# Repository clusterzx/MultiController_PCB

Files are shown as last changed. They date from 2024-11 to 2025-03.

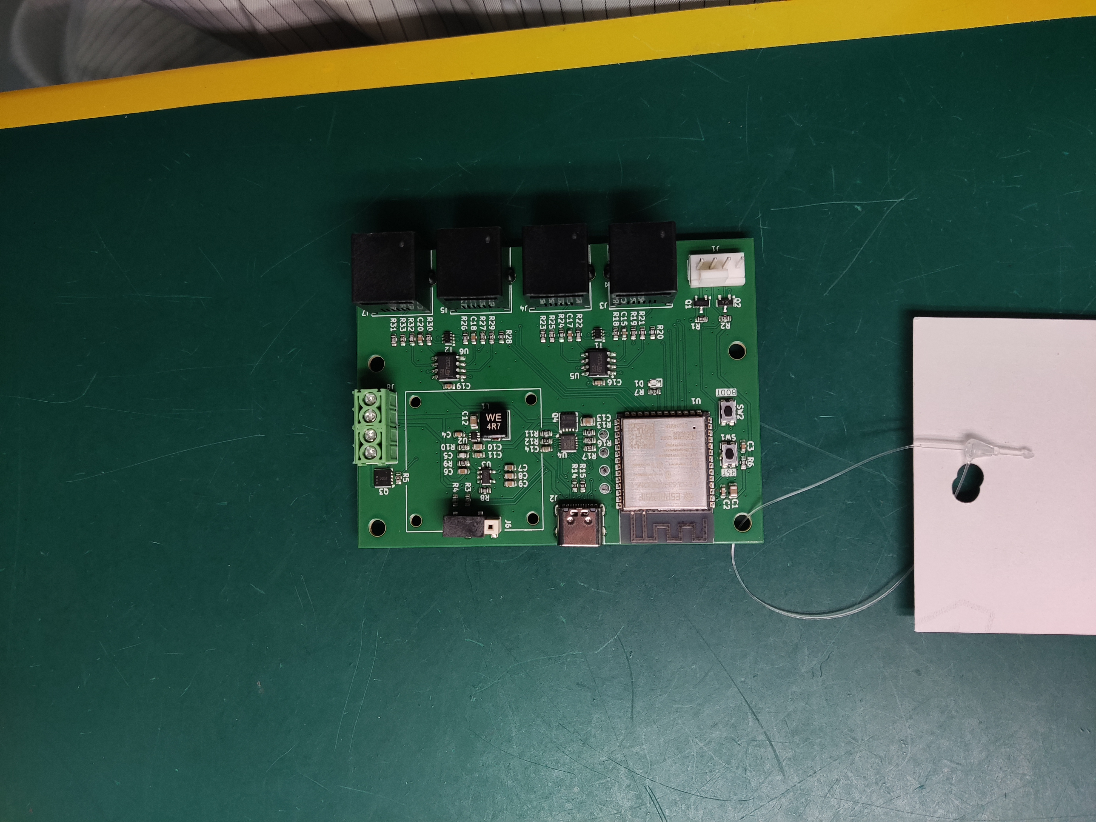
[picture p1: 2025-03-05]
Hardware/documentation/T-X20W345372A_JLCPCB/T-X20W345372A (5).jpg

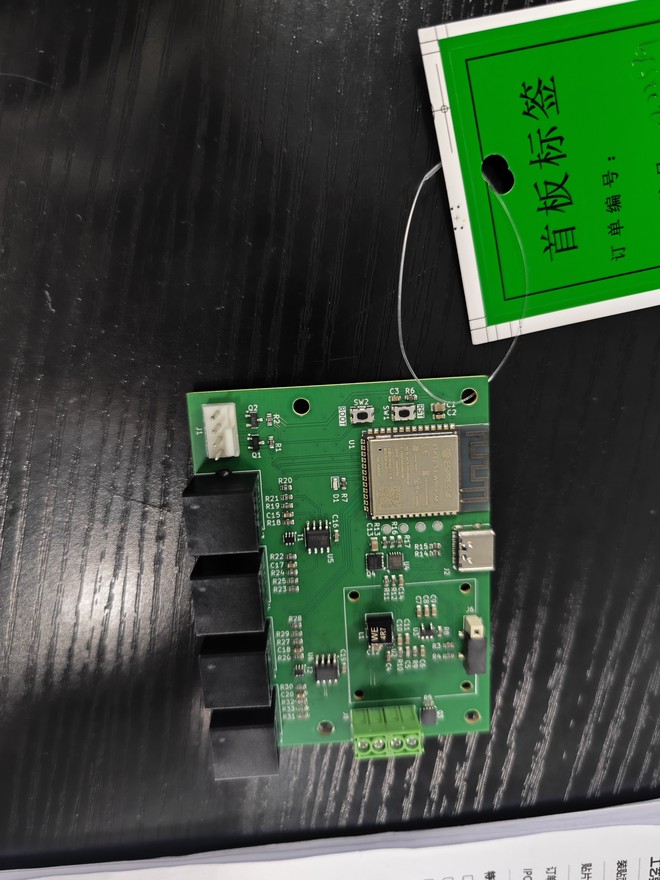
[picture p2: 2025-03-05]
Hardware/documentation/T-X20W345372A_JLCPCB/T-X20W345372A (1).jpg

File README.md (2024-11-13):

# MultiController_PCB
Design Files für Review Auftrag.

**Ziel des Controllers:**

 1. Steuerung von Geräten über PWM 0-10V und/oder DAC 0-10V . Die Geräte bekommen ihre Spannungsversorgugn von einer externen Quelle (somit reines Steuersignal)
 2. Steuerung von handelsüblichen PC Fans (PWM) über den Molexanschluss (müssten 12V sein).
 3. Steuerung der PWM Signale unabhängig von einander. Bedeutet z.B. das auf RJ Jack 1 PWM 50% liegen und auf RJ 2 nichts dafür auf RJ 3-4 100%.
 4. Steuerung des Terminalblocks 3,5,12V (an/aus) (dort liegt immer nur 1 Verbraucher an)
 5. Anschluss eines optionalen OLED Displays und steuerung über ESP32

**ChatGPT generierte Zusammenfassung des Auftragschats:**
## Zusammenfassung

Dieses Dokument fasst die finalen Funktionen und Änderungen für das Multicontroller PCB-Projekt zusammen.

## Finalisierte Funktionen

1. **Spannungsversorgung**:
   - USB-C als primäre Stromquelle mit Power Delivery (PD) für 12V.
   - Step-Down-Konverter auf 5V und ein LDO (Low Dropout Regulator) auf 3.3V.
   - Optionaler Boost-Konverter für zusätzliche 12V, falls mehr Leistung benötigt wird.

2. **RJ14-Anschlüsse (6P4C)**:
   - Steuerung von Geräten über PWM und GND.
   - Modularer RJ14-Anschluss (6P4C) für Kompatibilität mit Standardkabeln (1:1 oder crossed).

3. **Schraubklemmen für stärkere Stromverbindungen**:
   - Verwendung von Phoenix-Klemmen, um dickere Kabel (z.B. AWG 14) anzuschließen.
   - Schraubklemmen mit 3.5mm Pitch für Zuverlässigkeit und eine robuste Verbindung.

4. **ESP32-S3 Mikrocontroller**:
   - Externer DAC hinzugefügt, da der ESP32-S3 keinen integrierten DAC hat.
   - Reset- und Boot-Knöpfe am Board integriert.
   - Alle benötigten GPIOs auf PWM-Kompatibilität überprüft.

5. **Steuerung von PC-Lüftern und anderen Geräten**:
   - 12V-Anschluss für PC-Lüftersteuerung (optional per Software schaltbar).
   - Mehrere PWM-Ausgänge sowie ein analoger Modus über eine Operationsverstärker- und Kondensator-Schaltung.

6. **Montagemöglichkeiten und Board-Größe**:
   - Boardgröße: 60 x 80 mm.
   - Befestigungslöcher an allen vier Ecken für einfache Gehäusemontage.
   - Layout so gestaltet, dass ein Gehäuse einfach konstruiert werden kann.

## Wichtige Änderungen im Verlauf

- **Änderung des PD-Controllers**: Der ursprünglich geplante PD-Controller (AP33771C) war nicht verfügbar; daher Wechsel zum besser verfügbaren HUSB238.
- **Änderungen an den RJ14-Buchsen**: Diskussion über verschiedene RJ-Typen (RJ11, RJ12, RJ14); endgültige Entscheidung für RJ14 mit 6P4C für bessere Kompatibilität.
- **Überarbeitung der Schraubklemmen**: Zunächst wurden filigrane Klemmen verwendet; später durch robustere Phoenix-Schraubklemmen ersetzt.
- **Dual-Assembly-Option**: Ursprünglich wurden zwei mögliche Bestückungsoptionen (JLCPCB und Aisler) in Betracht gezogen; aufgrund des Preisvorteils letztendlich für JLCPCB entschieden.
- **Optimierung des KiCad-Projekts**: Letzte Anpassungen und Testpunkte (TP) wurden geklärt; Bauteilzuordnungen für die Bestellung bei JLCPCB überprüft.

---

Diese Zusammenfassung bietet eine vollständige Übersicht über die finalen Funktionen und Änderungen, die im Verlauf des Projekts vorgenommen wurden.

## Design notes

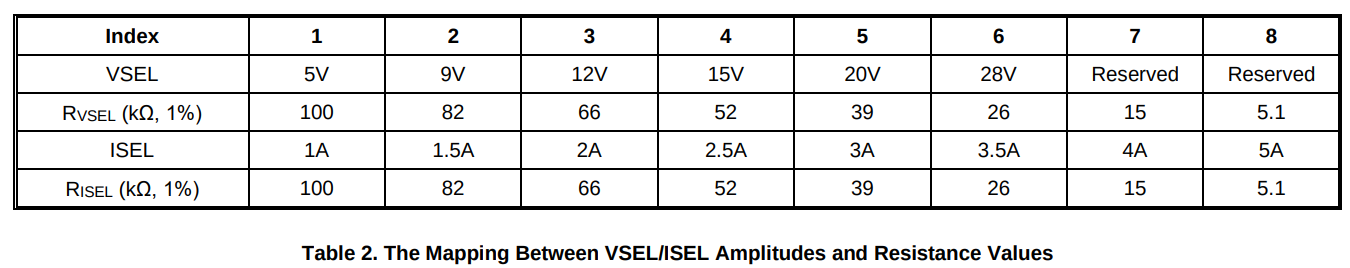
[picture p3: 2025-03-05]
Hardware/documentation/AP33771C_VSEL_ISEL.png

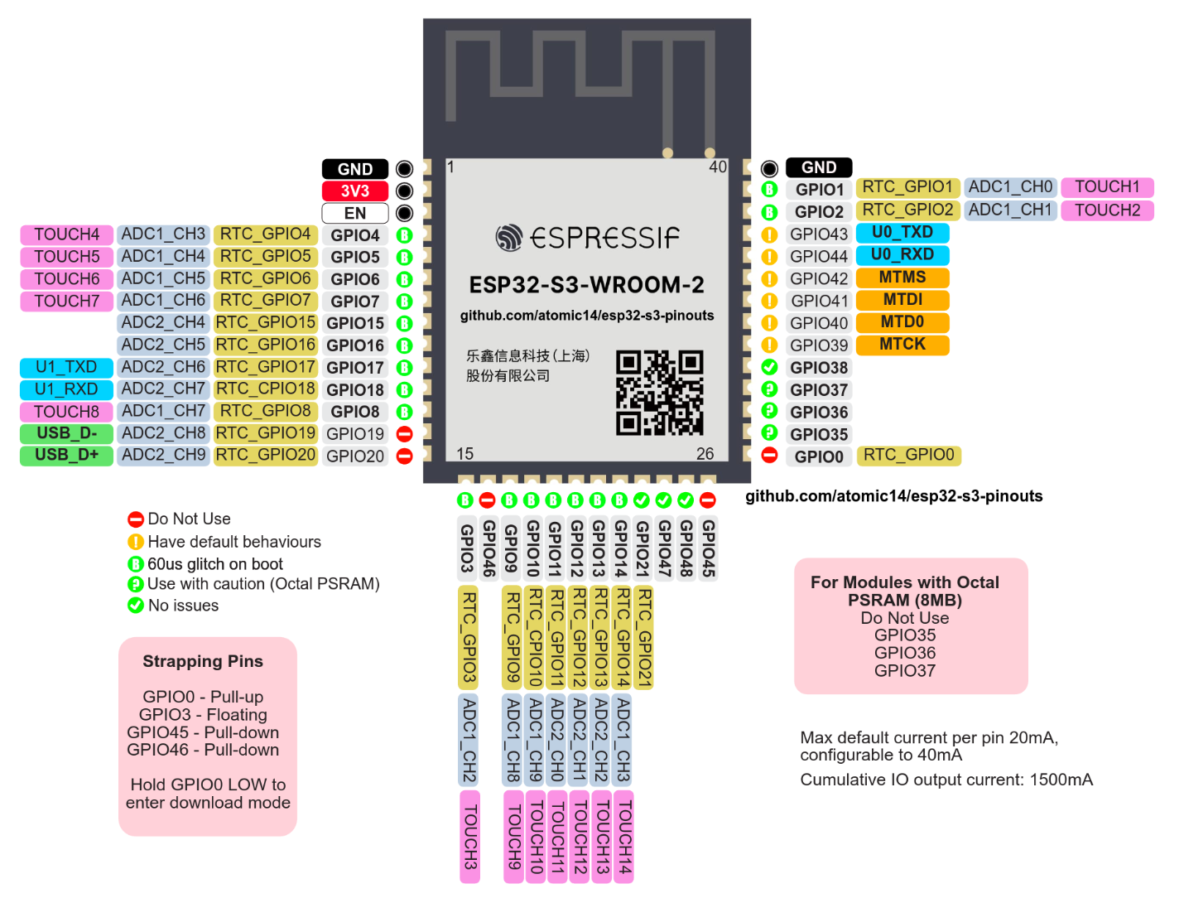
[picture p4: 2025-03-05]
Hardware/documentation/ESP32-S3-WROOM_pinout.png

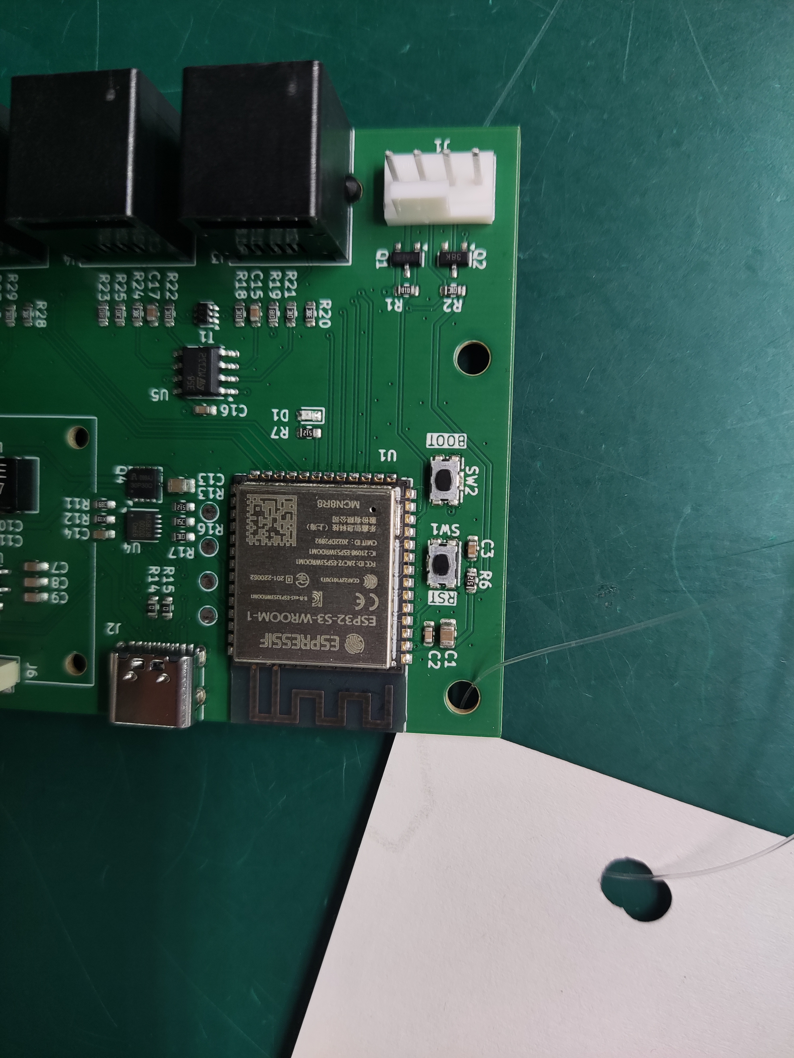
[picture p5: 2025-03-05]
Hardware/documentation/T-X20W345372A_JLCPCB/T-X20W345372A (7).jpg

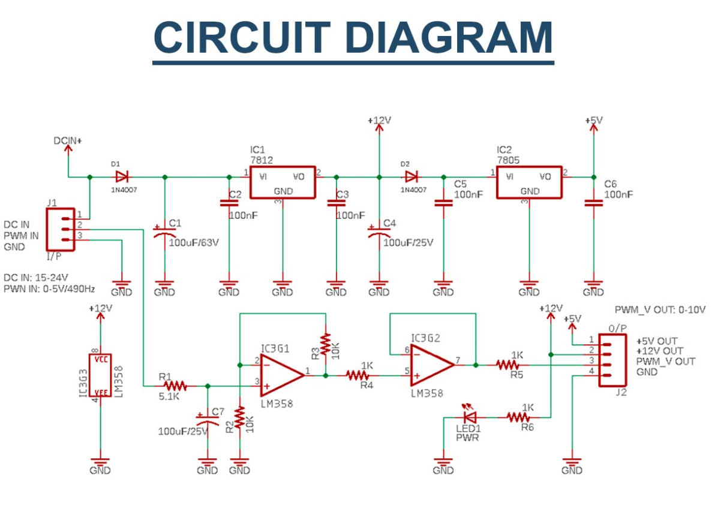
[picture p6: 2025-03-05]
Hardware/documentation/Amazon_PWMto0-10V.png

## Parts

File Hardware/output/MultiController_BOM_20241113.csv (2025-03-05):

Reference | Value | Footprint | Qty | DNP | JLCPCB Part # | MPN
C1,C12,C13 | 22u | Capacitor_SMD:C_0805_2012Metric | 3
C2,C4,C11,C16,C19 | 100n | Capacitor_SMD:C_0603_1608Metric | 5
C3,C14 | 1u | Capacitor_SMD:C_0603_1608Metric | 2
C5 | 22p | Capacitor_SMD:C_0603_1608Metric | 1
C6,C7,C8,C9,C10 | 10u | Capacitor_SMD:C_0603_1608Metric | 5
C15,C17,C18,C20 | 2u2 | Capacitor_SMD:C_0603_1608Metric | 4
D1 | KT-0603R | LED_SMD:LED_0603_1608Metric | 1 |  | C2286 | KT-0603R
J1 | PC-Fan | MultiController_customFP:Molex_KK-254_0470531000_1x04_P2.54mm_Vertical | 1 |  | C3025061 | 0470531000
J2 | USB_C_Receptacle_USB2.0_16P | Connector_USB:USB_C_Receptacle_XKB_U262-16XN-4BVC11 | 1 |  | C319148 | U262-161N-4BVC11
J3,J4,J5,J7 | 6P4C | MultiController_customFP:RJ14_ADAMTECH_MTJ-642BX2_Horizontal | 4 |  | C6600933 | MTJ-642BX2
J6 | OLED | MultiController_customFP:PinSocket_1x04_P2.54mm_Vertical_SMD_drill_Pin1Right | 1 |  | C7219867 | BG306-04-A-1-0400-L-B
J8 | Screw_Terminal_01x04 | TerminalBlock_Phoenix:TerminalBlock_Phoenix_PT-1,5-4-3.5-H_1x04_P3.50mm_Horizontal | 1 |  |  | 1984633
L1 | 4.7uH | Inductor_SMD:L_Wuerth_HCI-5040 | 1 |  | C2651181 | 744316470
Q1 | BSS83P | Package_TO_SOT_SMD:SOT-23 | 1 |  | C2932927 | BSS83PH6327
Q2 | BSS138 | Package_TO_SOT_SMD:SOT-23 | 1 |  | BSS138BK | C5224267
Q3 | DMN3008SFG | Package_SON:Diodes_PowerDI3333-8 | 1 |  | C384563 | DMN3008SFG-7
Q4 | AP30P30Q | Package_SON:Diodes_PowerDI3333-8 | 1 |  | C471913 | AP30P30Q
R1,R8 | 100k | Resistor_SMD:R_0603_1608Metric | 2
R2,R3,R4,R5,R10,R17,R18,R21,R22,R25,R26,R29,R30,R33 | 10k | Resistor_SMD:R_0603_1608Metric | 14
R6,R7,R13 | 5k1 | Resistor_SMD:R_0603_1608Metric | 3
R9 | 52k3 | Resistor_SMD:R_0603_1608Metric | 1
R11 | 49k9 | Resistor_SMD:R_0603_1608Metric | 1
R12 | 10r | Resistor_SMD:R_0603_1608Metric | 1
R14,R15 | 0r | Resistor_SMD:R_0603_1608Metric | 2
R16 | 14k | Resistor_SMD:R_0603_1608Metric | 1
R19,R23,R27,R31 | 1k | Resistor_SMD:R_0603_1608Metric | 4
R20,R24,R28,R32 | 20k | Resistor_SMD:R_0603_1608Metric | 4
SW1 | RESET | Button_Switch_SMD:SW_Push_1P1T_NO_CK_KMR2 | 1 |  | C72443 | KMR221GLFS
SW2 | BOOT | Button_Switch_SMD:SW_Push_1P1T_NO_CK_KMR2 | 1 |  | C72443 | KMR221GLFS
T1,T2 | BSS138DW | Package_TO_SOT_SMD:SOT-363_SC-70-6 | 2 |  | C5362112 | BSS138DW
U1 | ESP32-S3-WROOM-1 | MultiController_customFP:ESP32-S3-WROOM-1 | 1 |  | C2913201 | ESP32-S3-WROOM-1-N8R8
U2 | TPS562202 | Package_TO_SOT_SMD:SOT-563 | 1 |  | C2877547 | TPS562202
U3 | AP2112K-3.3 | Package_TO_SOT_SMD:SOT-23-5 | 1 |  | C51118 | AP2112K-3.3TRG1
U4 | HUSB238 | Package_DFN_QFN:DFN-10-1EP_3x3mm_P0.5mm_EP1.65x2.38mm | 1 |  | C7471904 | HUSB238_002DD
U5,U6 | LM358 | Package_SO:SOIC-8_3.9x4.9mm_P1.27mm | 2 |  | C9418 | LM358DT

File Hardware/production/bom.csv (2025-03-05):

Designator | Footprint | Quantity | Value | LCSC Part #
C1, C12, C13 | 0805 | 3 | 22u
C10, C6, C7, C8, C9 | 0603 | 5 | 10u
C11, C16, C19, C2, C4 | 0603 | 5 | 100n
C14, C3 | 0603 | 2 | 1u
C15, C17, C18, C20 | 0603 | 4 | 2u2
C5 | 0603 | 1 | 22p
D1 | 0603 | 1 | KT-0603R | C2286
J1 | Molex_KK-254_0470531000_1x04_P2.54mm_Vertical | 1 | PC-Fan | C3025061
J2 | USB_C_Receptacle_XKB_U262-16XN-4BVC11 | 1 | USB_C_Receptacle_USB2.0_16P | C319148
J3, J4, J5, J7 | RJ14_Connfly_DS1133-S4_Horizontal | 4 | 6P4C | C6600933
J6 | PinSocket_1x04_P2.54mm_Vertical_SMD_drill_Pin1Right | 1 | OLED | C7219867
J8 | TerminalBlock_Phoenix_PT-1,5-4-3.5-H_1x04_P3.50mm_Horizontal | 1 | Screw_Terminal_01x04 | 1984633
L1 | L_Wuerth_HCI-5040 | 1 | 4.7uH | C2651181
Q1 | SOT-23 | 1 | BSS83P | C2932927
Q2 | SOT-23 | 1 | BSS138 | BSS138BK
Q3 | Diodes_PowerDI3333-8 | 1 | DMN3008SFG | C384563
Q4 | Diodes_PowerDI3333-8 | 1 | AP30P30Q | C471913
R1, R8 | 0603 | 2 | 100k
R10, R17, R18, R2, R21, R22, R25, R26, R29, R30, R33, R5 | 0603 | 12 | 10k
R11 | 0603 | 1 | 49k9
R12 | 0603 | 1 | 10r
R13, R6, R7 | 0603 | 3 | 5k1
R14, R15 | 0603 | 2 | 0r
R16 | 0603 | 1 | 14k
R19, R23, R27, R31 | 0603 | 4 | 1k
R20, R24, R28, R32 | 0603 | 4 | 20k
R3, R4 | 0603 | 2 | 2k2
R9 | 0603 | 1 | 52k3
SW1 | SW_Push_1P1T_NO_CK_KMR2 | 1 | RESET | C72443
SW2 | SW_Push_1P1T_NO_CK_KMR2 | 1 | BOOT | C72443
T1, T2 | SOT-363_SC-70-6 | 2 | BSS138DW | C5362112
U1 | ESP32-S3-WROOM-1 | 1 | ESP32-S3-WROOM-1 | C2913201
U2 | SOT-563 | 1 | TPS562202 | C2877547
U3 | SOT-23-5 | 1 | AP2112K-3.3 | C51118
U4 | DFN-10-1EP_3x3mm_P0.5mm_EP1.65x2.38mm | 1 | HUSB238 | C7471904
U5, U6 | SOIC-8_3.9x4.9mm_P1.27mm | 2 | LM358 | C9418

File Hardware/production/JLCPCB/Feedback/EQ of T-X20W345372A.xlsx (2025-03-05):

T-X20W345372A-8sets
No. Item | Mfg Part | Package/Footprint | Description / Value | Designator | Qty per board | Total Qty | Qty Received | Instructions / Notes | Assembly Question | Reply from Customer
10 | MTJ-642BX2 | RJ14_ADAMTECH_MTJ-642BX2_Horizontal | 6P4C『 』RJ connector, 6P4C (6 positions 4 connected), RJ13/RJ14 | J3,J4,J5,J7 | 4 | 32 | 35 | C6600933 | We bought the component MTJ-642BX2, but it can't match the land pattern on the board. Please refer to the recommended design in the data-sheet, the distance marked in red should be 5.55mm, but you only designed it for 4.97mm in the Gerber file, so the pins can't be inserted into the holes. Please provide us a replacement component part number.
29 | KMR221GLFS | SW_Push_1P1T_NO_CK_KMR2 | RESET『 』Push button switch, generic, two pins | SW1 | 1 | 8 | 9 | C72443 | We bought the component KMR221GLFS, but it can't match the land pattern on the board. Please refer to the recommended design in the data-sheet, you designed one less pad in the Gerber file. Can we solder the component we bought? And please change the design in your next order.
30 | KMR221GLFS | SW_Push_1P1T_NO_CK_KMR2 | BOOT『 』Push button switch, generic, two pins | SW2 | 1 | 8 | 9 | C72443 | We bought the component KMR221GLFS, but it can't match the land pattern on the board. Please refer to the recommended design in the data-sheet, you designed one less pad in the Gerber file. Can we solder the component we bought? And please change the design in your next order.

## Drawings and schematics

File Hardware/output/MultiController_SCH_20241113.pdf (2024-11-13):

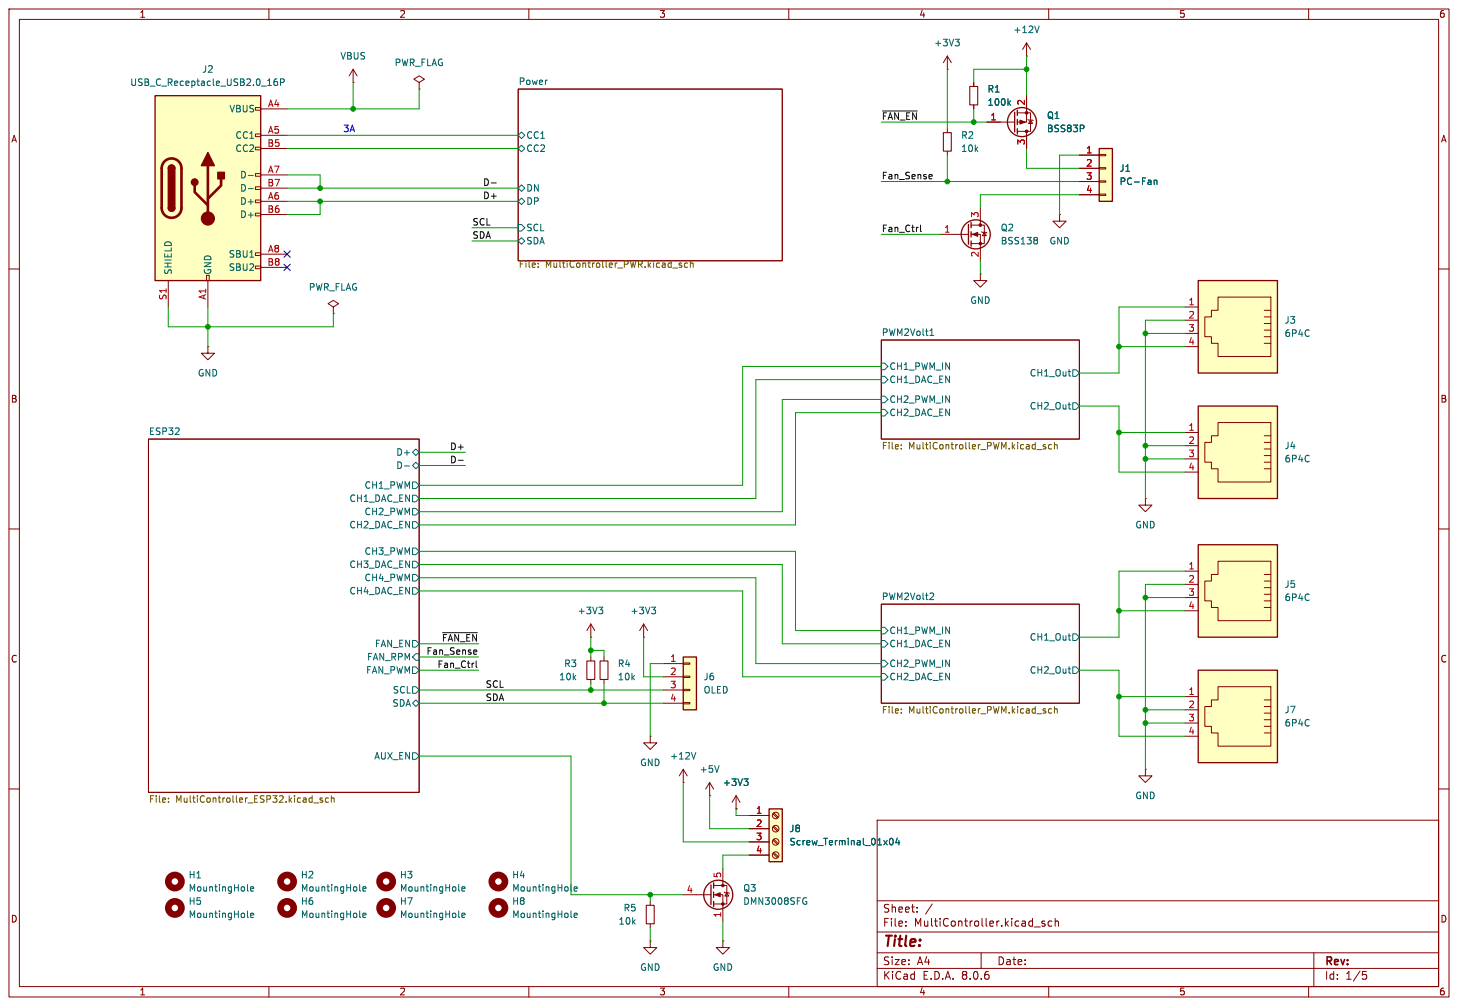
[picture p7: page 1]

Id: 1/5 Title: File: MultiController.kicad_sch Sheet: / D+D- SCL SDA CH1_PWM

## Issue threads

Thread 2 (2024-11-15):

Current limitation and trace width

olli177, 2024-11-15:
Following this calculation for the heating of PCB traces:

[ I[A] / (K x h[mm]^0,5 x b[mm]^0,64) ] ^2= ΔT[K] with K = 3,3 for 2-Layer PCBs and 2,25A as current value I[A]

The PCB trace of VBUS would heat up to ΔT[K] = 40 °C for 35um and ΔT[K] = 20°C for 70um

Idea: Increasing trace width to 0.5mm or even more would decrease the thermal heating by 10°C.

Knochi, 2024-11-19:
High Current paths track width increased to 0.6mm for VBus, 12V and +5V.

Closed 2024-11-19.

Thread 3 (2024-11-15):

I2C Pull-Up

olli177, 2024-11-15:
Reduce pull-up resistor from 10k to 2k2 (or even 1k) if using 400kHz I2C frequency.

Knochi, 2024-11-19:
done.

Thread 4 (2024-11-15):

J6 footprint

olli177, 2024-11-15:
J6 is a SMT variant with through holes?
Either use SMT pin header or THT pin header but two variants in one footprint?

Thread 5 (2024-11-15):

Optional: Avoid +12V on MCU

olli177, 2024-11-15:
Recommendation is to implement one npn transistor instead of using of low-active FAN_EN signal.
Deactivation of this signal (by pulling it High) would be by setting the corresponding GPIO to high-ohmic which is not really common.

With npn transistor, you can use setting the GPIO high (enable FAN) oder low (disable FAN).

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

clusterzx, 2024-11-19:
Resolved

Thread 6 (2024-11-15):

Silkscreen out of PCB dimensions

olli177, 2024-11-15:
The silkscreens of J3, J4, J5, J7 are not placed on the PCB so they are not printed on it during PCB production

Closed 2024-11-19.

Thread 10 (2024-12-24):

Molex Fan lässt sich nicht ausschalten / komisches Verhalten

clusterzx, 2024-12-24:
Wenn ich den 12V PWM Molexanschluss steuere ist bspw. der Lüfter bei 1% auf 960RPM, wenn ich dann auf 0% runter Regel dann ist RPM bei ca 3000 und er läuft viel schneller. Bei 99% ist der Lüfter auf ca 8000RPM, bei 100% fällt er ab auf 6000 und wird langsamer.

Zudem läuft der Lüfter ununterbrochen. Wie kann man den ausschalten? FAN_EN auf Low bringt nichts.

Knochi, 2025-01-05:
Noch mal hier.
Laut [Intel Spezifikation](https://www.intel.com/content/dam/support/us/en/documents/intel-nuc/intel-4wire-pwm-fans-specs.pdf) ist der PWM Bereich nur zwischen 20%-100% definiert. Bei  einem 0-PWM soll der Lüfter auf 100% hochdrehen.
Die Frequenz ist mit 25Hz +- 3Hz spezifiziert.

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

### FAN_EN
Hierüber kann die Spannungszufuhr zum Lüfter (pin2) gesteuert werden. Der Eingang ist Low-Activ, d.h. er muss auf Low gezogen werden, damit Q1 leitet. Ein HIGH genügt allerdings nicht, um den PMOS zum sperren bringen, da UGS dann immer noch -8.7V beträgt. UGS muss >2V sein. Dazu muss IO8 auf HIGH-Z (input ohne pullup) geschaltet werden. In einer Revision kann noch ein transistor zwischengeschaltet werden, der dann die Polarität umkehrt und HIGH/LOW pegel erlaubt.

### FAN_SENSE
Hier kann die aktuelle Drehzahl des Lüfters gemessen werden. Der Ausgang des Lüfters gibt zwei Pulse pro Umdrehung aus.

### FAN_CTRL
Hier kann ein PWM Signal angelegt werden um einen 4-pin Lüfter zu steuern. Die Frequenz sollt ebei 25Hz +-3Hz liegen. Der definierte Bereich liegt zwischen 20-100%. Bei 0-PWM dreht der Lüfter auf 100% (Notbetrieb).

Closed 2025-03-05.

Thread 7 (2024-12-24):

Voltage Drop mit FAN auf Ch1,2,3,4

clusterzx, 2024-12-24:
Szenario:

Ich kann ohne Probleme ein 0-10V PWM Signal erzeugen und steuern auf bspw. Ch1.
Sobald ich aber z.B. diesen Lüfter anschließe:
https://www.lueftungsmarkt.de/ruck-em-160-ec-02-rohrventilator

Droppt die Voltage von 10V auf 4.82V.

Antwort von ChatGPT:
# PWM-Problem mit Lüfter und ESP32

## Problem
Beim Betrieb des Lüfters kommt es zu einem Spannungsabfall am PWM-Ausgang von 10 V (ohne Lüfter) auf ca. 4,89 V (mit Lüfter).

## Vermutungen und mögliche Ursachen

### 1. LM358 als Operationsverstärker
- Der LM358 ist nicht "Rail-to-Rail"-fähig. Das bedeutet, dass die maximale Ausgangsspannung typischerweise 1–2 V unter der Versorgungsspannung (10 V) liegt, insbesondere unter Last.
- Der Spannungsabfall könnte verstärkt werden, wenn der Lüfter am Ausgang angeschlossen ist und der LM358 überlastet wird.

**Lösung:**
- Ersetzen des LM358 durch einen "Rail-to-Rail"-Operationsverstärker, z. B. **TSV321** oder **MCP6001**, der die Spannung näher an 10 V treiben kann.

---

### 2. Widerstandsnetzwerk (R19, R20, R21)
- Die Widerstände R20 (20 kΩ) und R21 (10 kΩ) legen eine Verstärkung von **3** fest. Bei einem Eingangssignal von 3,3 V ergibt das eine theoretische Ausgangsspannung von 9,9 V.
- Unter Last (z. B. durch den Lüfter) könnte der LM358 jedoch nicht genug Strom liefern, was die Spannung am Ausgang beeinträchtigt.

**Lösung:**
- Überprüfen, ob der LM358 durch einen Puffer (z. B. Transistor oder Treiber-IC) unterstützt werden muss, um die Last zu entkoppeln.
- Alternativ könnte ein stärkerer OPV mit höherer Strombelastbarkeit verwendet werden.

---

### 3. Pull-Up-Widerstand R18 und Kondensator C15
- **R18 (10 kΩ):** Bildet zusammen mit dem Eingangswiderstand des LM358 einen Spannungsteiler. Wenn der Wert von R18 zu hoch ist, kann dies die Spannung destabilisieren.
- **C15 (2,2 µF):** Glättet das PWM-Signal zu einer analogen Spannung. Ein zu kleiner Wert könnte dazu führen, dass die Spannung nicht stabil bleibt.

**Lösung:**
- Testen Sie größere Werte für C15, z. B. 10 µF, um die analoge Spannung weiter zu stabilisieren.
- Reduzieren Sie den Widerstand R18 auf z. B. 4,7 kΩ oder 1 kΩ, um den Spannungsteiler weniger empfindlich zu machen.

---

### 4. FET T1A (BSS138DW)
- Der MOSFET BSS138 könnte nicht vollständig durchschalten, was dazu führen kann, dass der Kondensator C15 nicht effizient entladen wird.
- Dies kann Spannungsverluste und instabiles Verhalten des PWM-Signals zur Folge haben.

**Lösung:**
- Sicherstellen, dass die Gate-Spannung des MOSFETs hoch genug ist, damit er vollständig durchschaltet.
- Alternativ einen leistungsstärkeren MOSFET verwenden, z. B. **IRLZ44N**.
- Überprüfen, ob ein Gate-Widerstand korrekt dimensioniert ist (falls vorhanden).

---

### 5. Lüfter als Last
- Der Lüftereingang könnte eine stabile Spannung erwarten, die von der aktuellen Schaltung nicht geliefert werden kann.
- Der Lüfter könnte zu viel Strom ziehen und den Ausgang des OPV überlasten.

**Lösung:**
- Am Ausgang des LM358 einen Pull-Up-Widerstand (z. B. 10 kΩ gegen 10 V) verwenden, um die Spannung zu stabilisieren.
- Einen separaten Puffer (z. B. NPN-Transistor oder Treiber-IC) hinzufügen, um die Last zu entkoppeln.

---

## Debugging-Schritte
1. **Spannung am LM358-Ausgang messen**, sowohl mit als auch ohne angeschlossenem Lüfter.
2. **PWM-Signalqualität prüfen**, z. B. mit einem Oszilloskop, um Störungen oder Spannungseinbrüche zu erkennen.
3. **Dummy-Last verwenden** (z. B. Widerstand), um die Lüfterlast zu simulieren und zu überprüfen, ob der Spannungsabfall auch ohne Lüfter auftritt.
4. **Stromverbrauch des Lüfters messen**, um sicherzustellen, dass die Schaltung die Last bewältigen kann.

---

## Fazit
Die Hauptursachen liegen vermutlich in der Strom- und Spannungsbegrenzung des LM358 sowie in der Dimensionierung der Beschaltung (z. B. C15, R18). Durch den Einsatz eines Rail-to-Rail-OPVs oder eines Puffers (Transistor/Treiber-IC) kann das Problem wahrscheinlich behoben werden.

Knochi, 2025-01-05:
Die OPs werden mit 12V versorgt, es sollte also genügend reserve geben.
Vermutlich belastet der Lüfter den Ausgang zu stark. Alleine der 1k Widerstand am Ausgang des OB hat schon einen Spannungsabfall von 1V/1mA.

(Lass das mit ChatGPT, frag mich einfach ;-) )

Knochi, 2025-03-05:
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

Changed to 0r

Closed 2025-03-05.

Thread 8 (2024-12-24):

LED Board leuchtet bei 0% weiter

clusterzx, 2024-12-24:
Folgendes Szenario:

Wenn ich bspw. diese Lampe steuern möchte:
https://www.viparspectra.com/products/xs-series-xs1000
dann fällt folgendes auf.

Die Lampe lässt sich problemlos bis 100% steuern. ABER bei 0% bleibt diese trotzdem noch leicht am leuchten.
Nach Messung mit Multimeter ist eine Restspannung von ca. ~500mV vorhanden.

Kann es daran liegen das ich die Lampe nicht komplett ausschalten kann?
Oder habe ich einen Fehler in dem Code bzw. etwas vergessen was ich noch ansteuern kann/muss damit auch wirklich 0.000 V anliegen?

Hier der Beispiel Code den ich mir hab generieren lassen (zum testen):
```c++
#include <WiFi.h>
#include <WebServer.h>
#include <EEPROM.h>

// WLAN Zugangsdaten
const char* ssid = "extender";      // Hier WLAN-Namen einsetzen
const char* password = "xxxxxx";    // Hier WLAN-Passwort einsetzen

// Pin Konfiguration
const int pwmPin = 9;            // GPIO09 als PWM-Ausgang (CH1_PWM)
const int enablePin = 11;        // GPIO11 als Enable Pin (CH1_DAC_EN)
const int pwmFreq = 5000;        // 5 kHz PWM Frequenz
const int pwmChannel = 0;        // PWM Kanal 0
const int pwmResolution = 8;     // 8-bit Auflösung (0-255)
float currentVoltage = 6.5;      // Startwert 6.5V

// Webserver auf Port 80
WebServer server(80);

// HTML für die Webseite (unverändert)
const char index_html[] PROGMEM = R"rawliteral(
<!DOCTYPE HTML>
<html>
<head>
  <meta name="viewport" content="width=device-width, initial-scale=1">
  <style>
    html { font-family: Arial; display: inline-block; text-align: center; }
    h2 { font-size: 2.3rem; }
    p { font-size: 1.9rem; }
    body { max-width: 400px; margin:0px auto; padding-bottom: 25px; }
    .slider { -webkit-appearance: none; width: 300px; height: 25px; background: #FFD65C;
      outline: none; -webkit-transition: .2s; transition: opacity .2s; }
    .slider::-webkit-slider-thumb { -webkit-appearance: none; appearance: none;
      width: 35px; height: 35px; background: #003249; cursor: pointer; }
    .slider::-moz-range-thumb { width: 35px; height: 35px; background: #003249; cursor: pointer; }
  </style>
</head>
<body>
  <h2>ESP32 PWM Steuerung</h2>
  <p>Spannung: <span id="voltageValue">6.5</span>V</p>
  <p><input type="range" min="0" max="100" step="1" value="65" class="slider" id="voltageSlider"></p>
  <p>Duty Cycle: <span id="dutyCycleValue">50</span>%</p>

  <script>
    var slider = document.getElementById("voltageSlider");
    var voltageText = document.getElementById("voltageValue");
    var dutyCycleText = document.getElementById("dutyCycleValue");

    // Initialisierung
    slider.value = %VOLTAGE_PERCENT%;
    voltageText.innerHTML = (slider.value / 10).toFixed(1);
    dutyCycleText.innerHTML = slider.value;

    slider.oninput = function() {
      voltageText.innerHTML = (this.value / 10).toFixed(1);
      dutyCycleText.innerHTML = this.value;
      var xhr = new XMLHttpRequest();
      xhr.open("GET", "/setVoltage?value="+this.value, true);
      xhr.send();
    }
  </script>
</body>
</html>
)rawliteral";

void setup() {
  // Serielle Kommunikation starten
  Serial.begin(115200);
  delay(1000);

  Serial.println("\n\nStarting ESP32 PWM Webserver...");

  // Pin Konfiguration
  Serial.println("Konfiguriere Pins...");
  pinMode(enablePin, OUTPUT);
  ledcSetup(pwmChannel, pwmFreq, pwmResolution);
  ledcAttachPin(pwmPin, pwmChannel);

  // Setze Startwert
  setVoltageOutput(currentVoltage);
  Serial.println("PWM konfiguriert!");

  // WLAN Verbindung herstellen
  Serial.printf("Verbinde mit WLAN %s", ssid);
  WiFi.begin(ssid, password);

  int timeout = 0;
  while (WiFi.status() != WL_CONNECTED && timeout < 30) {
    delay(500);
    Serial.print(".");
    timeout++;
  }

  if (WiFi.status() != WL_CONNECTED) {
    Serial.println("\nWLAN-Verbindung fehlgeschlagen!");
    Serial.println("Neustart in 5 Sekunden...");
    delay(5000);
    ESP.restart();
  }

  Serial.println("\nWiFi verbunden!");
  Serial.print("IP Adresse: ");
  Serial.println(WiFi.localIP());

  // Webserver Routen definieren
  Serial.println("Konfiguriere Webserver...");
  server.on("/", HTTP_GET, handleRoot);
  server.on("/setVoltage", HTTP_GET, handleVoltage);

  // Webserver starten
  server.begin();
  Serial.println("Webserver gestartet!");
  Serial.println("Setup abgeschlossen!");
}

void loop() {
  server.handleClient();
}

// Funktion zum Setzen der Ausgangsspannung
void setVoltageOutput(float voltage) {
  if (voltage <= 0.0) {
    // Ausgang deaktivieren
    digitalWrite(enablePin, LOW);  // MOSFET ausschalten
    ledcWrite(pwmChannel, 0);     // PWM auf 0
    Serial.println("Ausgang deaktiviert (0V)");
  } else {
    // Ausgang aktivieren und Spannung setzen
    digitalWrite(enablePin, HIGH); // MOSFET einschalten
    int dutyCycle = (voltage * 255) / 10.0;  // Umrechnung in Duty Cycle
    ledcWrite(pwmChannel, dutyCycle);
    Serial.printf("Spannung auf %.1fV gesetzt (Duty Cycle: %d%%)\n",
                 voltage,
                 int(voltage * 10));
  }
}

// Handler für die Hauptseite
void handleRoot() {
  String html = String(index_html);
  html.replace("%VOLTAGE_PERCENT%", String(currentVoltage * 10));
  server.send(200, "text/html", html);
  Serial.println("Webseite aufgerufen");
}

// Handler für Spannungsänderungen
void handleVoltage() {
  if (server.hasArg("value")) {
    float percentage = server.arg("value").toFloat();
    currentVoltage = percentage / 10.0;  // Umrechnung in Volt
    setVoltageOutput(currentVoltage);
    server.send(200, "text/plain", "OK");
  }
}

Closed 2025-03-05.

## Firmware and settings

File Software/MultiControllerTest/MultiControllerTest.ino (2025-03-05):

#include <WiFi.h>
#include <WebServer.h>
#include <EEPROM.h>
#include <Wire.h>
#include <Adafruit_GFX.h>
#include <Adafruit_SSD1306.h>

#define SCREEN_WIDTH 128
#define SCREEN_HEIGHT 64
#define OLED_RESET -1
#define SCREEN_ADDRESS 0x3C
#define ESP32VER 3 //enter major version of ESP32 arduino board

Adafruit_SSD1306 display(SCREEN_WIDTH, SCREEN_HEIGHT, &Wire, OLED_RESET);

// WLAN credentials
const char* ssid = "LV426";
const char* password = "19263854466404343353";

// Pin definitions for Molex Fan
const int MOLEX_PWM_PIN = 1;     // GPIO1 for PWM
const int MOLEX_RPM_PIN = 2;     // GPIO2 for RPM signal
const int AUX_EN_PIN = 38;       // GPIO38 for switch
const int MOLEX_EN_PIN = 8;

// Pin definitions for 0-10V Fan
const int CH1_PWM_PIN = 9;    // GPIO9 for Channel1 Output
const int CH1_DC_EN_PIN = 11; // GPIO11 to enable DC mode
const int CH2_PWM_PIN = 12;    // GPIO9 for Channel1 Output
const int CH2_DC_EN_PIN = 10; // GPIO11 to enable DC mode
const int CH3_PWM_PIN = 14;    // GPIO9 for Channel1 Output
const int CH3_DC_EN_PIN = 47; // GPIO11 to enable DC mode
const int CH4_PWM_PIN = 48;    // GPIO9 for Channel1 Output
const int CH4_DC_EN_PIN = 21; // GPIO11 to enable DC mode

// PWM configuration for Molex Fan
const int MOLEX_PWM_FREQ = 12000;  // 25 kHz
const int MOLEX_PWM_CHANNEL = 0;
const int MOLEX_PWM_RESOLUTION = 8;

// PWM configuration for 0-10V Fan
const int CH1_PWM_FREQ = 5000;   // 5 kHz
const int CH1_PWM_CHAN = 1;
const int CH1_PWM_RES = 8;

WebServer server(80);

// Global variables
volatile unsigned long lastPulseTime = 0;
volatile unsigned int pulseCount = 0;
unsigned int rpm = 0;
int molexFanSpeed = 0;           // Current speed for Molex fan (0-100%)
float analogFanVoltage = 6.5;    // Current voltage for 0-10V fan

// Interrupt Service Routine for RPM measurement
void IRAM_ATTR rpmISR() {
  pulseCount++;
}

void updateDisplay() {
  display.clearDisplay();
  display.setTextSize(1);
  display.setTextColor(SSD1306_WHITE);
  
  // IP address
  display.setCursor(0,0);
  display.print("IP: ");
  display.println(WiFi.localIP());
  
  // Molex fan speed
  display.setCursor(0,16);
  display.print("Molex: ");
  display.print(molexFanSpeed);
  display.println("%");
  
  // Analog fan voltage
  display.setCursor(0,32);
  display.print("0-10V: ");
  display.print(analogFanVoltage, 1);
  display.println("V");
  
  // RPM
  display.setCursor(0,48);
  display.print(rpm);
  display.println(" RPM");
  
  display.display();
}

void setup() {
  Serial.begin(115200);
  delay(1000);
  
  // Initialize OLED
  Wire.begin(6, 5);
  if(!display.begin(SSD1306_SWITCHCAPVCC, SCREEN_ADDRESS)) {
    Serial.println(F("SSD1306 allocation failed"));
    for(;;);
  }

  Serial.println("Starting...");
  display.clearDisplay();
  display.setTextColor(SSD1306_WHITE);
  display.setTextSize(1);
  display.setCursor(0,0);
  display.println("Starting...");
  display.display();
  
  // Initialize EEPROM
  EEPROM.begin(512);
  
  // Load saved values
  molexFanSpeed = EEPROM.read(0);
  if(molexFanSpeed > 100) molexFanSpeed = 50;
  
  analogFanVoltage = EEPROM.readFloat(4);
  if(analogFanVoltage < 0 || analogFanVoltage > 10) analogFanVoltage = 6.5;
  
  // Configure Aux Pin
  pinMode(AUX_EN_PIN, OUTPUT);
  digitalWrite(AUX_EN_PIN, LOW);

  // Configure Molex fan pins
  pinMode(MOLEX_RPM_PIN, INPUT_PULLUP);
  pinMode(MOLEX_EN_PIN, OUTPUT);
  digitalWrite(MOLEX_EN_PIN, LOW);
  
  // Configure 0-10V fan pins
  pinMode(CH1_DC_EN_PIN, OUTPUT);
  pinMode(CH1_PWM_PIN, OUTPUT);
  pinMode(CH2_DC_EN_PIN, OUTPUT);
  pinMode(CH2_PWM_PIN, OUTPUT);
  pinMode(CH3_DC_EN_PIN, OUTPUT);
  pinMode(CH3_PWM_PIN, OUTPUT);
  pinMode(CH4_DC_EN_PIN, OUTPUT);
  pinMode(CH4_PWM_PIN, OUTPUT);

  
  // Configure PWM channels
  #if ESP32VER < 3
    ledcSetup(MOLEX_PWM_CHANNEL, MOLEX_PWM_FREQ, MOLEX_PWM_RESOLUTION);
    ledcAttachPin(MOLEX_PWM_PIN, MOLEX_PWM_CHANNEL);

    ledcSetup(CH1_PWM_CHAN, CH1_PWM_FREQ, CH1_PWM_RES);
    ledcAttachPin(CH1_PWM_PIN, CH1_PWM_CHAN);
    ledcSetup(CH2_PWM_CHAN, CH1_PWM_FREQ, CH1_PWM_RES);
    ledcAttachPin(CH2_PWM_PIN, CH1_PWM_CHAN);
    ledcSetup(CH3_PWM_CHAN, CH1_PWM_FREQ, CH1_PWM_RES);
    ledcAttachPin(CH3_PWM_PIN, CH1_PWM_CHAN);
    ledcSetup(CH4_PWM_CHAN, CH1_PWM_FREQ, CH1_PWM_RES);
    ledcAttachPin(CH4_PWM_PIN, CH1_PWM_CHAN);
  #else
    //analogWriteFrequency(MOLEX_PWM_PIN,MOLEX_PWM_FREQ);
    if (ledcAttach(MOLEX_PWM_PIN,MOLEX_PWM_FREQ,MOLEX_PWM_RESOLUTION)){
      Serial.println("Sucessfully attached Molex PWM");
    }
    if (ledcAttach(CH1_PWM_PIN,CH1_PWM_FREQ,CH1_PWM_RES))
      Serial.println("Sucessfully attached CH1 PWM");
    if (ledcAttach(CH2_PWM_PIN,CH1_PWM_FREQ,CH1_PWM_RES))
      Serial.println("Sucessfully attached CH2 PWM");
    if (ledcAttach(CH3_PWM_PIN,CH1_PWM_FREQ,CH1_PWM_RES))
      Serial.println("Sucessfully attached CH3 PWM");
    if (ledcAttach(CH4_PWM_PIN,CH1_PWM_FREQ,CH1_PWM_RES))
      Serial.println("Sucessfully attached CH4 PWM");
    
    
    
    Serial.print("Molex Fan Freq: ");
    Serial.println(ledcReadFreq(MOLEX_PWM_PIN));
    Serial.print("ledc clock source: "); 
  attachInterrupt(digitalPinToInterrupt(MOLEX_RPM_PIN), rpmISR, FALLING);
  
  // Connect to WiFi
  WiFi.begin(ssid, password);
  display.clearDisplay();
  display.setCursor(0,0);
  display.println("Connecting WiFi...");
  display.display();
  
  while (WiFi.status() != WL_CONNECTED) {
    delay(500);
    Serial.print(".");
  }
  
  // Define web server routes
  server.on("/", handleRoot);
  server.on("/setMolexSpeed", handleSetMolexSpeed);
  server.on("/setAnalogVoltage", handleSetAnalogVoltage);
  server.on("/getData", handleGetData);
  server.on("/switch", handleSwitch);
  server.begin();
  
  updateDisplay();
}

void loop() {
  server.handleClient();
  
  static unsigned long lastDisplayUpdate = 0;
  static unsigned long lastRpmCalc = 0;
  
  // Calculate RPM every 500ms
  if(millis() - lastRpmCalc >= 500) {
    rpm = (pulseCount * 60);
    pulseCount = 0;
    lastRpmCalc = millis();
  }
  
  // Update display every 1000ms
  if(millis() - lastDisplayUpdate >= 1000) {
    updateDisplay();
    lastDisplayUpdate = millis();
  }
}

//set all Voltages to the same value for now
void setAnalogFanVoltage(float voltage) {
  if (voltage <= 0.0) {
    ledcWrite(CH1_PWM_PIN, 0);
    ledcWrite(CH2_PWM_PIN, 0);
    ledcWrite(CH3_PWM_PIN, 0);
    ledcWrite(CH4_PWM_PIN, 0);
  } else {
    digitalWrite(CH1_DC_EN_PIN, HIGH); //analog mode
    digitalWrite(CH2_DC_EN_PIN, HIGH); //analog mode
    digitalWrite(CH3_DC_EN_PIN, HIGH); //analog mode
    digitalWrite(CH4_DC_EN_PIN, HIGH); //analog mode

    int dutyCycle = (voltage * 255) / 10.0;
    ledcWrite(CH1_PWM_PIN, dutyCycle);
    ledcWrite(CH2_PWM_PIN, dutyCycle);
    ledcWrite(CH3_PWM_PIN, dutyCycle);
    ledcWrite(CH4_PWM_PIN, dutyCycle);

  }
}

void handleRoot() {
  String html = "<!DOCTYPE html>\n"
                "<html>\n"
                "<head>\n"
                    "<title>Fan Control System</title>\n"
                    "<meta name=\"viewport\" content=\"width=device-width, initial-scale=1\">\n"
                    "<style>\n"
                        "body { font-family: Arial; text-align: center; margin: 20px; }\n"
                        ".slider { width: 80%; max-width: 400px; }\n"
                        ".control-group { margin: 30px 0; }\n"
                        "button { padding: 10px 20px; margin: 5px; }\n"
                    "</style>\n"
                "</head>\n"
                "<body>\n"
                    "<h1>Fan Control System</h1>\n"
                    "<div class=\"control-group\">\n"
                        "<h2>Molex Fan Control</h2>\n"
                        "<input type=\"range\" min=\"0\" max=\"100\" value=\"" + String(molexFanSpeed) + "\" class=\"slider\" id=\"molexSlider\">\n"
                        "<p>Speed: <span id=\"molexValue\">" + String(molexFanSpeed) + "</span>%</p>\n"
                        "<p>RPM: <span id=\"rpmValue\">" + String(rpm) + "</span></p>\n"
                        "<p>\n"
                            "<button onclick=\"switchGPIO(1)\">GPIO 38 ON</button>\n"
                            "<button onclick=\"switchGPIO(0)\">GPIO 38 OFF</button>\n"
                        "</p>\n"
                    "</div>\n"
                    "<div class=\"control-group\">\n"
                        "<h2>0-10V Control</h2>\n"
                        "<input type=\"range\" min=\"0\" max=\"100\" value=\"" + String(analogFanVoltage * 10) + "\" class=\"slider\" id=\"analogSlider\">\n"
                        "<p>Voltage: <span id=\"analogValue\">" + String(analogFanVoltage) + "</span>V</p>\n"
                    "</div>\n"
                    "<script>\n"
                        "var molexSlider = document.getElementById('molexSlider');\n"
                        "var analogSlider = document.getElementById('analogSlider');\n"
                        "var molexValue = document.getElementById('molexValue');\n"
                        "var analogValue = document.getElementById('analogValue');\n"
                        "var rpmValue = document.getElementById('rpmValue');\n"
                        
                        "molexSlider.oninput = function() {\n"
                            "molexValue.innerHTML = this.value;\n"
                            "fetch('/setMolexSpeed?speed=' + this.value);\n"
                        "};\n"
                        
                        "analogSlider.oninput = function() {\n"
                            "let voltage = (this.value / 10).toFixed(1);\n"
                            "analogValue.innerHTML = voltage;\n"
                            "fetch('/setAnalogVoltage?voltage=' + voltage);\n"
                        "};\n"

                        
                        "function switchGPIO(state) {\n"
                            "fetch('/switch?state=' + state);\n"
                        "}\n"
                        
                        "setInterval(function() {\n"
                            "fetch('/getData')\n"
                            ".then(response => response.json())\n"
                            ".then(data => {\n"
                                "rpmValue.innerHTML = data.rpm;\n"
                                "molexValue.innerHTML = data.molexSpeed;\n"
                                "analogValue.innerHTML = data.analogVoltage;\n"
                                "molexSlider.value = data.molexSpeed;\n"
                                "analogSlider.value = data.analogVoltage * 10;\n"
                            "});\n"
                        "}, 500);\n"
                    "</script>\n"
                "</body>\n"
                "</html>\n";
  server.send(200, "text/html", html);
}

void handleSetMolexSpeed() {
  static bool wasOn=true;
  Serial.print("Set Fan Speed: ");
  
  if(server.hasArg("speed")) {
    molexFanSpeed = server.arg("speed").toInt();
    molexFanSpeed = constrain(molexFanSpeed, 0, 100);
    Serial.println(molexFanSpeed);

    if(molexFanSpeed == 0) {
      ledcWrite(MOLEX_PWM_PIN, 0);
      //pinMode(MOLEX_EN_PIN, INPUT); //set to High-Z
      Serial.println("Fan OFF");
      digitalWrite(MOLEX_EN_PIN, LOW);
    } else {
      digitalWrite(MOLEX_EN_PIN, HIGH);
      //ledcWrite(MOLEX_PWM_PIN, map(molexFanSpeed, 0, 100, 255, 0));
      analogWrite(MOLEX_PWM_PIN, map(molexFanSpeed, 0, 100, 255, 0));
    }
    
    EEPROM.write(0, molexFanSpeed);
    EEPROM.commit();
    
    server.send(200, "text/plain", "OK");
  }
}

void handleSetAnalogVoltage() {
  if(server.hasArg("voltage")) {
    analogFanVoltage = server.arg("voltage").toFloat();
    analogFanVoltage = constrain(analogFanVoltage, 0, 10);
    
    setAnalogFanVoltage(analogFanVoltage);
    
    EEPROM.writeFloat(4, analogFanVoltage);
    EEPROM.commit();
    
    server.send(200, "text/plain", "OK");
  }
}

void handleSwitch() {
  if(server.hasArg("state")) {
    if(server.arg("state") == "1") {
      digitalWrite(AUX_EN_PIN, HIGH);
    } else {
      digitalWrite(AUX_EN_PIN, LOW);
    }
    server.send(200, "text/plain", "OK");
  }
}

void handleGetData() {
  String json = "{\"molexSpeed\":" + String(molexFanSpeed) + 
                ",\"analogVoltage\":" + String(analogFanVoltage) + 
                ",\"rpm\":" + String(rpm) + "}";
  server.send(200, "application/json", json);
}

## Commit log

2025-01-12 some changes to make ledc work. renamed constants to reflect their usage
2025-03-05 added PCB data
    [BOM_MultiController.kicad_pcb_241203.xls, EQ of T-X20W345372A.xlsx, MultiController.csv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]
2025-03-05 fix #10
    [MultiController.kicad_pcb]
2025-03-05 changed references
    [MultiController_ESP32.kicad_sch, MultiController_FAN.kicad_sch]
2025-03-05 changed OP Amps to Rail-to-Rail type fix #8
    [MultiController.kicad_pcb, MultiController_ESP32.kicad_sch, MultiController_PWM.kicad_sch]
2025-03-05 fixed references
    [MultiController.kicad_pcb, MultiController_ESP32.kicad_sch, MultiController_FAN.kicad_sch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]
